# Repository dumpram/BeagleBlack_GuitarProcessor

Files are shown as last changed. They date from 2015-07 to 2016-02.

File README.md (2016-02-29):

# Guitar Sound Processing on BeagleBone Black Platform

## Content

1. Source files for digital sound processing
2. BeagleBone Audio Cape schematics
3. Prototype

## 1. Source files for digital sound processing
Digital sound processing is dependent on JACK library and all necessary dependencies can be installed
by executing setup.sh script. Ensure that you have internet connection on BeagleBone Black over USB or
Ethernet interface. 

Main program is DEP_main which can be built by executing make in Digital_effects_processor directory.
For controlling parameters of digital sound processing use AudioRack application which is Node.Js. 
application.

## 2. BeagleBone Audio Cape schematics 
Audio Cape schematics can be found in Schematics directory. They were created with Altium Designer 14.

## 3. Prototype
Below you can see images of prototype Digital Guitar Effects processor:

###Cape board
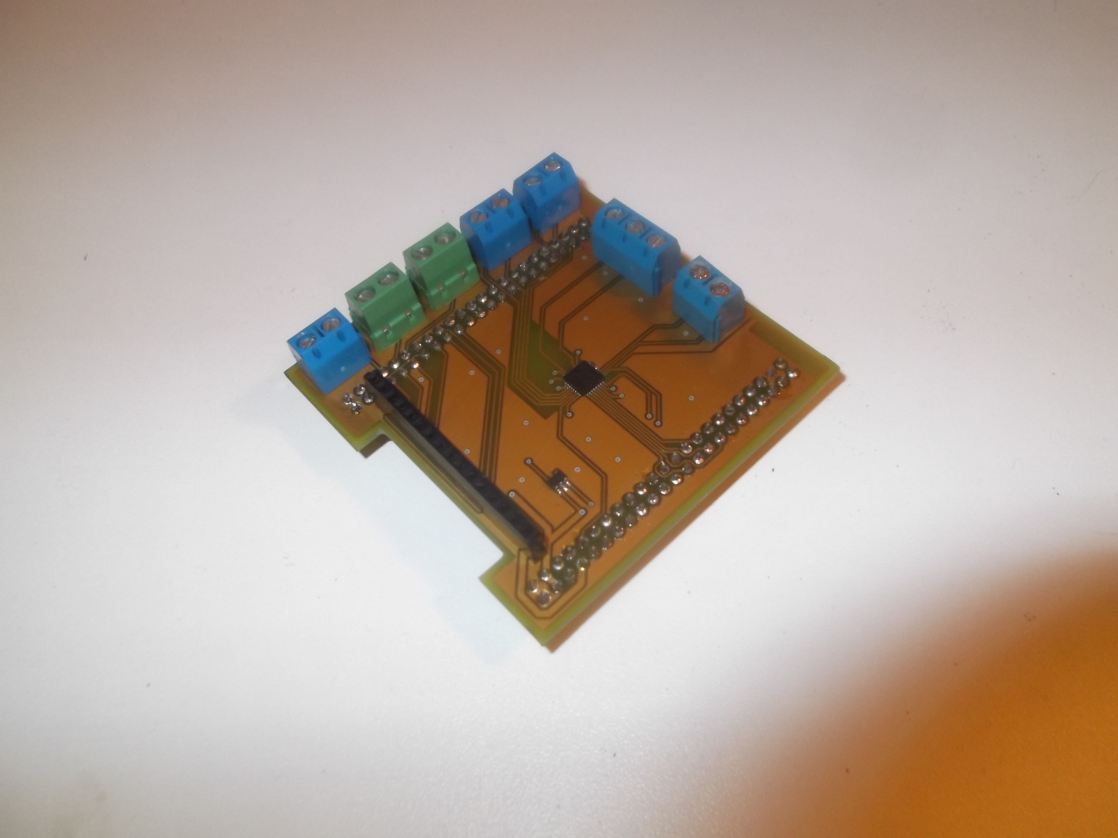
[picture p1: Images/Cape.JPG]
Cape board


###Cape board installed on BeagleBone Black
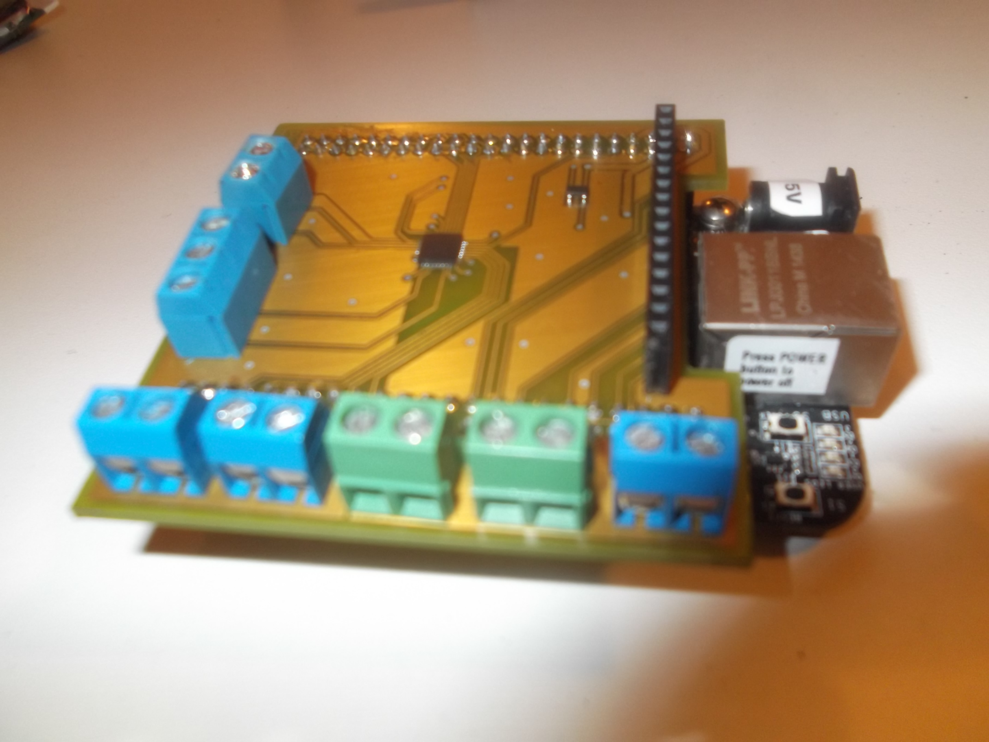
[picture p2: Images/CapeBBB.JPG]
Cape board installed on BeagleBone Black


###Installing BeagleBone Black in box 1
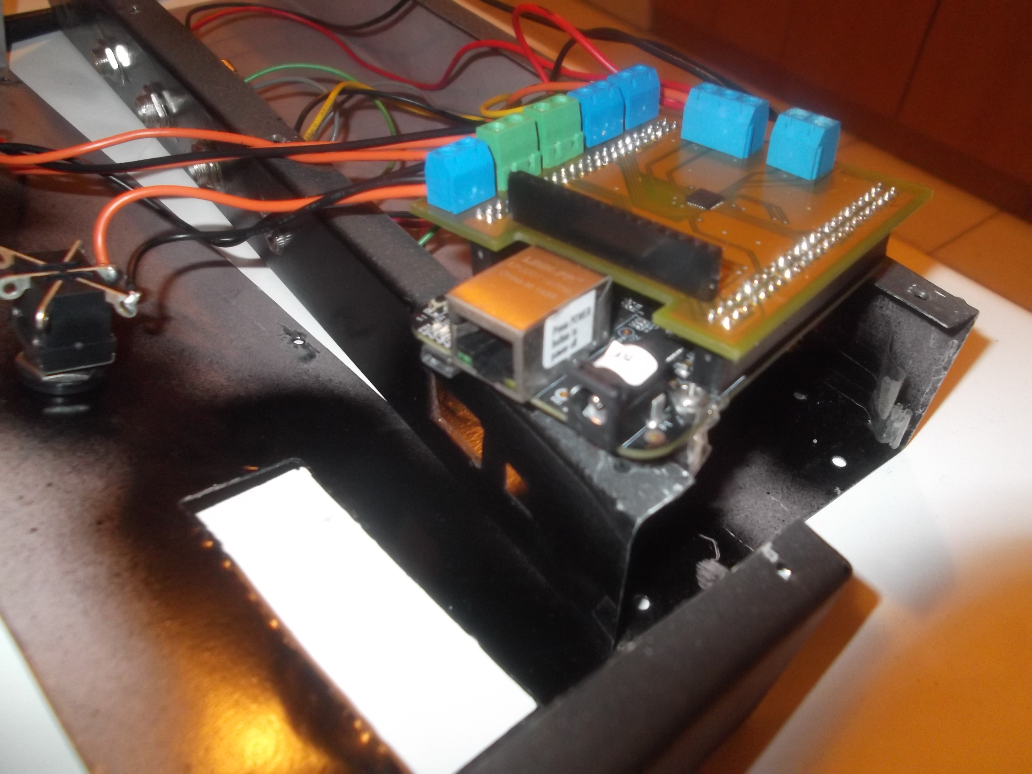
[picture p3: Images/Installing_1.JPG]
Installing BeagleBone Black in box 1


###Installing BeagleBone Black in box 2
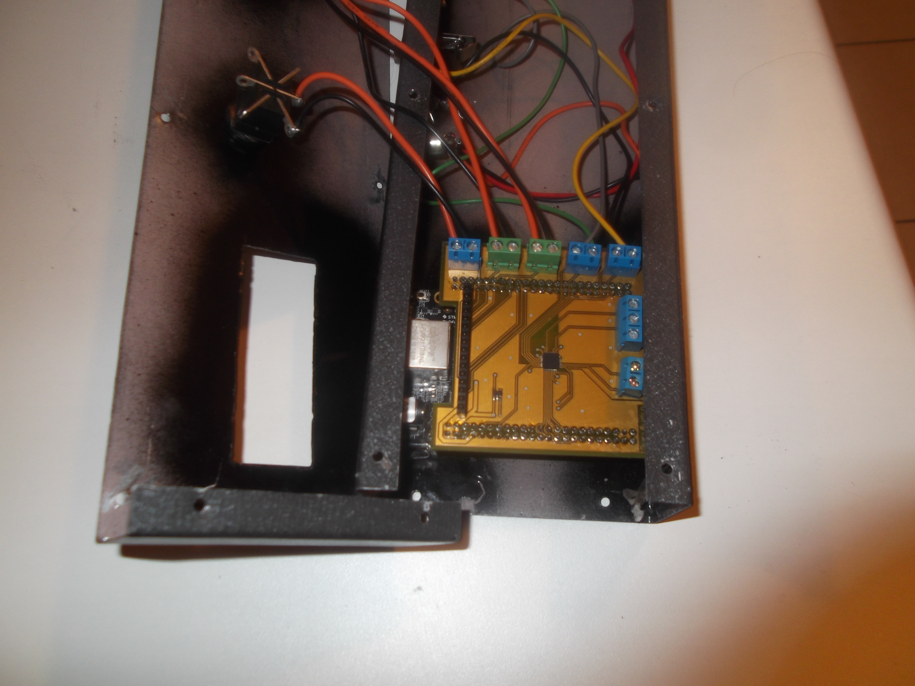
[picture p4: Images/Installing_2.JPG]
Installing BeagleBone Black in box 2


###Installing BeagleBone Black in box 3
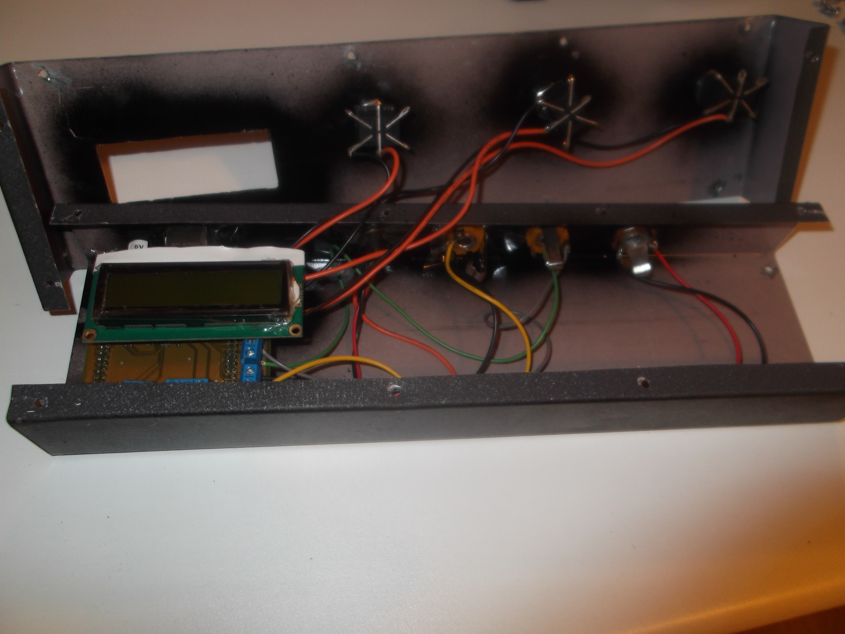
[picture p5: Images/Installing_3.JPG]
Installing BealgeBone Black in box 3


###Final look
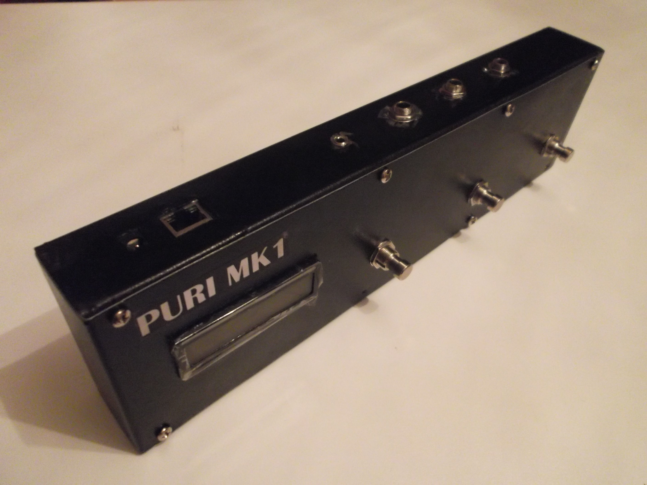
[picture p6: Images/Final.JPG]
Final look


###Test Ride 
https://www.youtube.com/watch?v=q_JOzhX_dxE

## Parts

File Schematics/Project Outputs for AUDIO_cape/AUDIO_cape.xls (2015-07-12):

Cijena | Comment | Description | Designator | Dobavljač | Footprint | Kataloški broj | Quantity
11.28 | TPS76918 | LDO regulator napona | A1 | Farnell | DBV005 | 8461503 | 1
0.41 | 10u | Keramički kondezator | C1, C15, C16 | Farnell | 6-0805_N | 3019949 | 3
0.41 | 100n | Keramički kondezator | C2, C5, C6, C7, C17, C18 | Farnell | 6-0805_N | 3019949 | 6
1.31 | Ferit | Feritna jezgra | L1, L2 | Farnell | 6-0805_N | 1635735 | 2
0.17 | 10k | Otpornik | R1, R2, R3 | Farnell | 6-0805_M | 9332391 | 3
1.67 | SW-PB | Stezaljka 2P | S1, S2, S3, X1, X2, X3 | Chipoteka | STEZALJKA_2P_5MM | 2630505010 | 6
6.58 | LCD 16x2 | LCD priključak - ženski strip | H1 | Chipoteka | SIP16 | 4090010001 | 1
3.31 | BeagleBone | DIL priključak - muški strip | D1 | Chipoteka | BBB_CAPE | 4090004001 | 2
2.37 | headphone_output | Stezaljka 3P | J2 | Chipoteka | STEZALJKA_3P_5MM | 2630505012 | 1

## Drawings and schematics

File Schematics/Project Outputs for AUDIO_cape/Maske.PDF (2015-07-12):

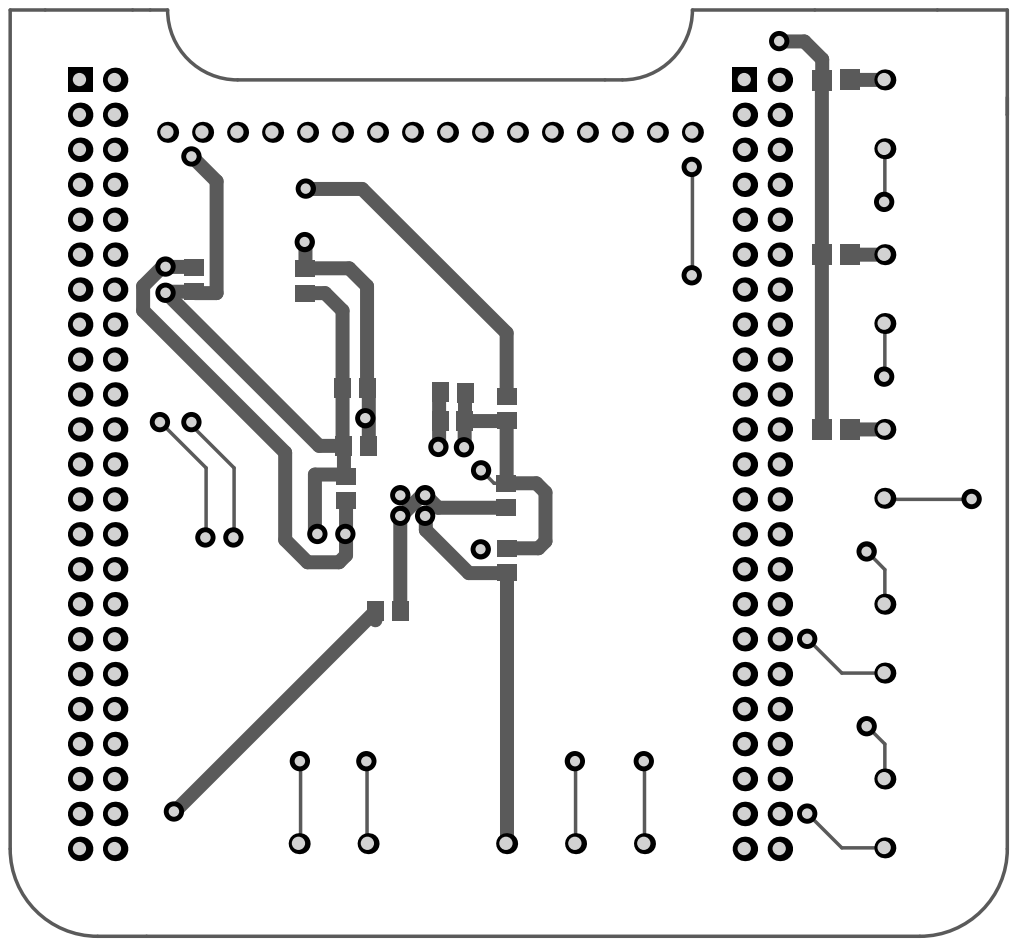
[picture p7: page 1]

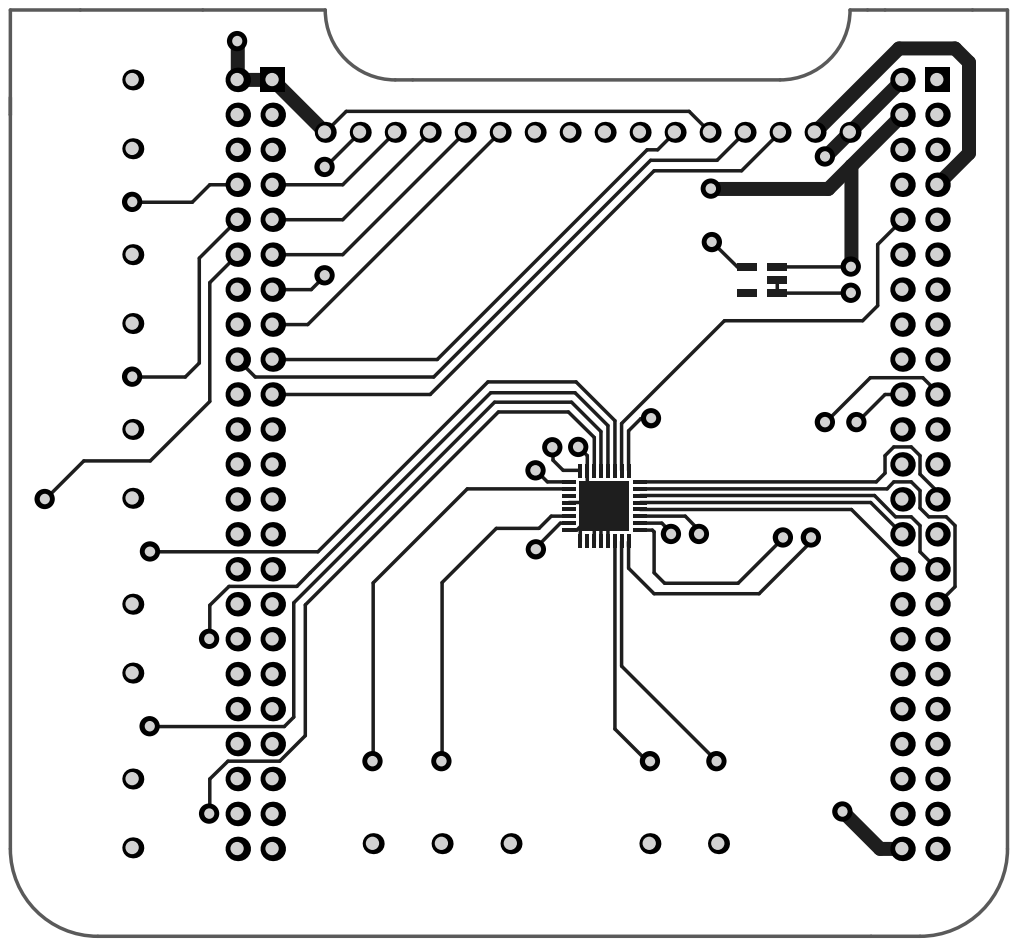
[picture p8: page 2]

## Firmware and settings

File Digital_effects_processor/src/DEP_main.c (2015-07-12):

/** @file DEP_main.c
 *
 * @brief main file of of Digital Effects Processor application.
 * @author Ivan Pavic
 * @version 1.0.1.
 */

/** Header with all necessary declarations **/
#include <DEP.h>

/** Global audio port pointers **/
static audio_port_t *input_port;
static audio_port_t *output_port;

/* Application is visible as client to JACK audio server */
audio_client_t *client;

/**
 * Function gets audio sample data from input port. It delegates data to all 
 * observers and processes it. After processing data is sent to output port.
 */
int process(nframes_t nframes, void *arg) {
    /** Pointers to memory locations of input and output samples **/

    audio_sample_t *input, *output;
    processor_t *processor = (processor_t *) arg;
    input = jack_port_get_buffer (input_port, nframes);
    output = jack_port_get_buffer (output_port, nframes);
    
    /** Digital Signal Processing **/
    digital_signal_processing(input, processor);
   
    /** Copying files to output memory location **/ 
    memcpy(output, input, sizeof(audio_sample_t) * nframes);
    
    return 0;
}

void jack_shutdown(void *arg) {
    exit(1);
}

/**
 * Initializes and runs JACK audio client. Connects physical audio input
 * to input of JACK audio client. Additionally it connects output of client
 * to left and right playback port.
 */
void initAudioClient(processor_t *processor) {
    const char **ports;
	const char *client_name = "DEP";
	const char *server_name = NULL;
	jack_options_t options = JackNullOption;
	jack_status_t status;
	
	/* Open a client connection to the JACK server */
	client = jack_client_open (client_name, options, &status, server_name);
	if (client == NULL) {
		fprintf (stderr, "jack_client_open() failed, "
			 "status = 0x%2.0x\n", status);
		if (status & JackServerFailed) {
			fprintf (stderr, "Unable to connect to JACK server\n");
		}
		exit (1);
	}
	
	if (status & JackServerStarted) {
		fprintf (stderr, "JACK server started\n");
	}
	if (status & JackNameNotUnique) {
		client_name = jack_get_client_name(client);
		fprintf (stderr, "unique name `%s' assigned\n", client_name);
	}

	/* Set callback function for client. Function will be called every cycle */
	jack_set_process_callback (client, process, processor);

	/* Set shutdown function for client. Function will be called on shutdown */
	jack_on_shutdown (client, jack_shutdown, 0);

	/* Create two ports(global) */
	input_port = jack_port_register (client, "input",
					 JACK_DEFAULT_AUDIO_TYPE,
					 JackPortIsInput, 0);
	output_port = jack_port_register (client, "output",
					  JACK_DEFAULT_AUDIO_TYPE,
					  JackPortIsOutput, 0);
					  
	if ((input_port == NULL) || (output_port == NULL)) {
		fprintf(stderr, "no more JACK ports available\n");
		exit (1);
	}
	
	/* Activate JACK client. Callback function will be called every cycle */
	if (jack_activate (client)) {
		fprintf (stderr, "cannot activate client");
		exit (1);
	}
	/* Connect the ports. Connects client's ports to physical inputs and outputs */
	ports = jack_get_ports (client, NULL, NULL,
				JackPortIsPhysical|JackPortIsOutput);
	if (ports == NULL) {
		fprintf(stderr, "no physical capture ports\n");
		exit (1);
	}
	if (jack_connect (client, ports[0], jack_port_name (input_port))) {
		fprintf (stderr, "cannot connect input ports\n");
	}
	ports = jack_get_ports (client, NULL, NULL,
				JackPortIsPhysical|JackPortIsInput);
	if (ports == NULL) {
		fprintf(stderr, "no physical playback ports\n");
		exit (1);
	}
	if (jack_connect (client, jack_port_name (output_port), ports[0])) {
		fprintf (stderr, "cannot connect output ports\n");
	}
	
	if (jack_connect (client, jack_port_name (output_port), ports[1])) {
		fprintf (stderr, "cannot connect output ports\n");
	}
	free (ports);
}
/**
 * Function intializes processor structure which is description of whole system 
 * for digital sound processing. Additionally it starts JACK audio client and 
 * server.
 */
void initProcessor(processor_t *processor) {
	init_digital_effects();
	switch_init();
	processor -> switch_id_list[0] = SWITCH_GPIO_1;
	processor -> switch_id_list[1] = SWITCH_GPIO_2;
	processor -> switch_id_list[2] = SWITCH_GPIO_3;
	processor -> reverb = create_reverb();
	processor -> dist = create_distortion();
   	processor -> lcd = create_lcd();
   	double qFactor = 1/sqrt(2);
   	double qFactorL = 0.001;
   	processor -> filter[0] = create_biquad_filter(peak_eq_filter, 64, 0, qFactorL);
   	processor -> filter[1] = create_biquad_filter(peak_eq_filter, 125, 0, qFactorL);
   	processor -> filter[2] = create_biquad_filter(peak_eq_filter, 250, 0, qFactorL);
   	processor -> filter[3] = create_biquad_filter(peak_eq_filter, 500, 0, qFactorL);
   	processor -> filter[4] = create_biquad_filter(peak_eq_filter, 1000, 0, qFactorL);
   	processor -> filter[5] = create_biquad_filter(peak_eq_filter, 2000, 0, qFactor);
   	processor -> filter[6] = create_biquad_filter(peak_eq_filter, 4000, 0, qFactor);
   	processor -> filter[7] = create_biquad_filter(peak_eq_filter, 8000, 0, qFactor);
	initAudioClient(processor);
}


/**
 * Main function of application. Registers inputs and outputs in OS and connects 
 * them. If necessary JACK server will be started. Additionally, threads for 
 * frequency analysis, IPC communication and GPIO changes are started.
 */
int main() {
	pthread_t switch_handler, ipc_rack_handler, freq_analysis_handler;
	processor_t processor;
    initProcessor(&processor);
    
   	if(pthread_create(&switch_handler, NULL, switch_monitor, &processor)) {
   		perror("Couldn't create 'switch_monitor' thread!");
   	}
   	if(pthread_create(&ipc_rack_handler, NULL, ipc_audio_effects, &processor)) {
   		perror("Couldn't create 'ipc_audio_effects' thread!");
   	}
   	if(pthread_create(&freq_analysis_handler, NULL, tuner_task, &processor)) {
   	 	perror("Couldn't create 'tuner_task' thread!");
   	}
    sleep(-1);
	return 0;	
}
 

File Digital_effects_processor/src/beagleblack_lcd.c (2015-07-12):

/** @file beagleblack_lcd.h
 *
 * @brief source file for LCD1602A library for BeagleBone Black. Contains implementations 
 *	of functions. Documentation can be found in beagleblack_lcd.h header file. 
 * @author Ivan Pavic
 * @version 1.0
 */
#include "beagleblack_lcd.h"

void lcd_init(lcd_pinout *lcd) {
    gpio_init(lcd -> en, "out", '0');
    gpio_init(lcd -> rs, "out", '0');
    gpio_init(lcd -> db_7, "out", '0');
    gpio_init(lcd -> db_6, "out", '0');
    gpio_init(lcd -> db_5, "out", '0');
    gpio_init(lcd -> db_4, "out", '0');

    lcd_com(lcd, 0x33); 
    lcd_com(lcd, 0x32);

    lcd_com(lcd, LCD_DISPLAYCONTROL |  LCD_DISPLAYON | LCD_CURSOROFF | LCD_BLINKOFF);
    lcd_com(lcd, LCD_FUNCTIONSET | LCD_4BITMODE | LCD_1LINE | LCD_2LINE | LCD_5x8DOTS);
    lcd_com(lcd, LCD_ENTRYMODESET | LCD_ENTRYLEFT | LCD_ENTRYSHIFTDECREMENT);
    lcd_clear(lcd);
}

void lcd_clear(lcd_pinout *lcd) {
    lcd_com(lcd, LCD_CLEARDISPLAY);
    usleep(4000);
}

void lcd_print(lcd_pinout *lcd, char *message) {
    int i, len;
    len = strlen(message);
    for (i = 0; i < len; i++) {
        lcd_delay();
        lcd_data(lcd, message[i]);
    }
}

void lcd_data(lcd_pinout *lcd, char message) {
    gpio_set_value(lcd -> rs, '1');
    lcd_send(lcd, message);
}

void lcd_new_line(lcd_pinout *lcd) {
    lcd_com(lcd, LCD_SETDDRAMADDR | LCD_2nd_ROW_OFFSET);
}

void lcd_set_cursor(lcd_pinout *lcd, int row, int col) {
    if (!row) {
        lcd_com(lcd, LCD_SETDDRAMADDR | col);
    } else {
        lcd_com(lcd, LCD_SETDDRAMADDR | (col + LCD_2nd_ROW_OFFSET));
    }
} 

void lcd_com(lcd_pinout *lcd, char message) {
    gpio_set_value(lcd -> rs, '0');
    lcd_send(lcd, message);
}

void lcd_send(lcd_pinout *lcd, char message) {
    char upper_bits = (message & 0xF0) >> 4;
    char lower_bits = (message & 0x0F);
    char value;
    
    value = ((upper_bits >> 3) & 0x1)? '1' : '0';
    gpio_set_value(lcd -> db_7, value);
    
    value = ((upper_bits >> 2) & 0x1)? '1' : '0';
    gpio_set_value(lcd -> db_6, value);
    
    value = ((upper_bits >> 1) & 0x1)? '1' : '0';
    gpio_set_value(lcd -> db_5, value);
    
    value = ((upper_bits >> 0) & 0x1)? '1' : '0';
    gpio_set_value(lcd -> db_4, value);
    
    lcd_toggle_enable(lcd);
    
    value = ((lower_bits >> 3) & 0x1)? '1' : '0';
    gpio_set_value(lcd -> db_7, value);
    
    value = ((lower_bits >> 2) & 0x1)? '1' : '0';
    gpio_set_value(lcd -> db_6, value);
    
    value = ((lower_bits >> 1) & 0x1)? '1' : '0';
    gpio_set_value(lcd -> db_5, value);
    
    value = ((lower_bits >> 0) & 0x1)? '1' : '0';
    gpio_set_value(lcd -> db_4, value);
    
    lcd_toggle_enable(lcd);
     
}

void lcd_delay() {
    int i = LCD_TOGGLE_ENABLE_DELAY;
    while(i--);

}

void lcd_toggle_enable(lcd_pinout *lcd) {
    gpio_set_value(lcd -> en, '0');
    lcd_delay();
    gpio_set_value(lcd -> en, '1');
    lcd_delay();
    gpio_set_value(lcd -> en, '0');
}

void lcd_deinit(lcd_pinout *lcd) {
    gpio_unexport(lcd -> en);
    gpio_unexport(lcd -> rs);
    gpio_unexport(lcd -> db_7);
    gpio_unexport(lcd -> db_6);
    gpio_unexport(lcd -> db_5);
    gpio_unexport(lcd -> db_4);
}
